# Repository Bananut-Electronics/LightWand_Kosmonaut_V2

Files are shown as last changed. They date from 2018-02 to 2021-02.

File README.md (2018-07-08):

# LightWand_Kosmonaut_V2

Welcome to the LightWand_Kosmonaut_V2 repository. Careful traveller! It is still under development

This _Wiki_ covers the _**LightWand Kosmonaut V2**_ lightpainting tool, an _Open Source_, cheap, easy to made and modify machine tu help the user make awesome detailled photographs through the lightpainting technique.



# What is the LightWand Kosmonaut V2?
The _**LightWand Kosmonaut V2(LWK2)**_ is an Arduino based device which can control LED Stripes in order to display images stored in an SD card. Additionally, it has a number of additional features to use it as a sensor data display device or a simple pattern generator for lightpainting photography.

# So, if this one is V2... where is V1?
The _**LightWand Kosmonaut V1(LWK1)**_ was developped by Pablo dMM in 2015 (The same guy that developped this one) and the repository can be found here:

https://github.com/PabloDMM/LightWand_KosmonautEd

This project was originally based on the first _LightWand_ made by _**Michael Ross**_ in 2014 (http://mrossphoto.com/wordpress32/), please check out his awesome work. The LWK1 inherited form this version the main concept and two SW functions (described in code).

It is a similar tool to the commercial product _**Pixelstick**_ (http://www.thepixelstick.com/).

# Show me what can be done with it.
These are some photos made with this tools, and that should guide you an idea of what is it and how could it be used. None of these photos are processed (further that contrast and brightness and perhaps saturation):

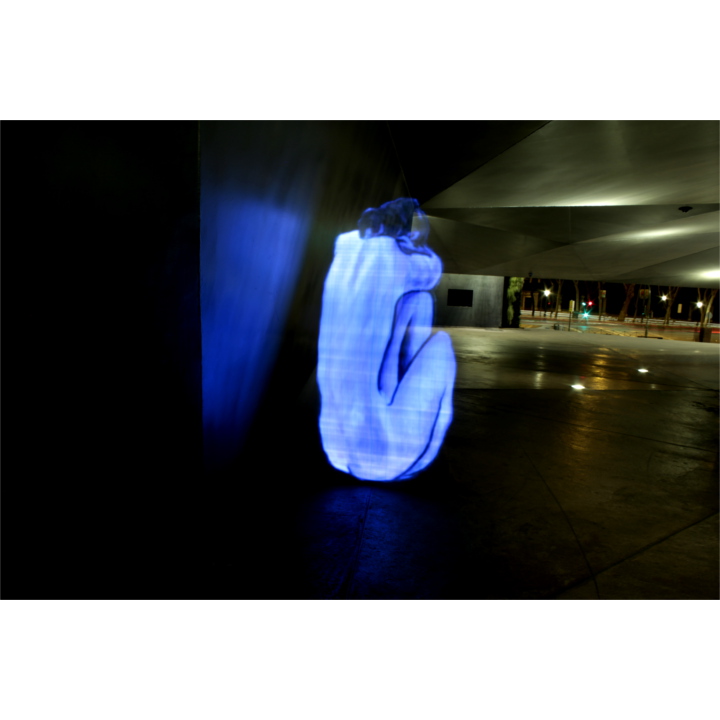
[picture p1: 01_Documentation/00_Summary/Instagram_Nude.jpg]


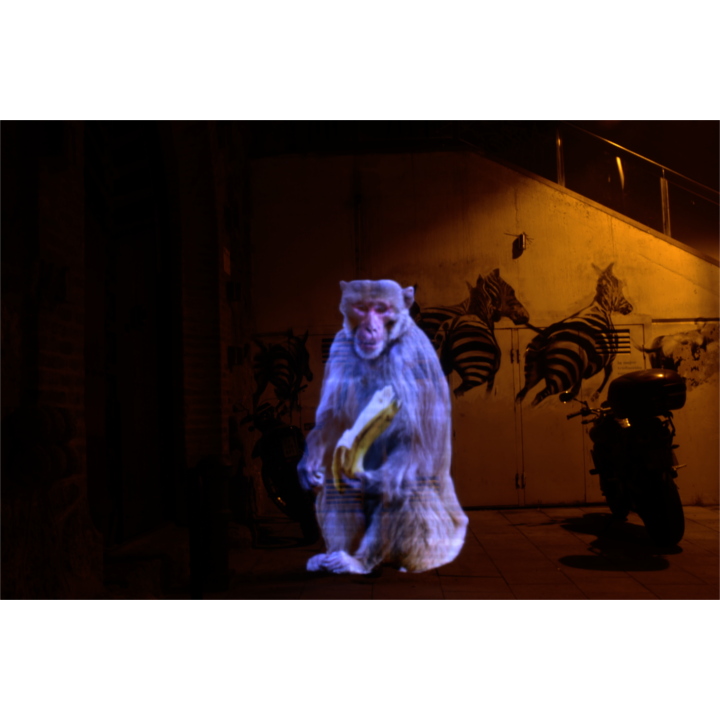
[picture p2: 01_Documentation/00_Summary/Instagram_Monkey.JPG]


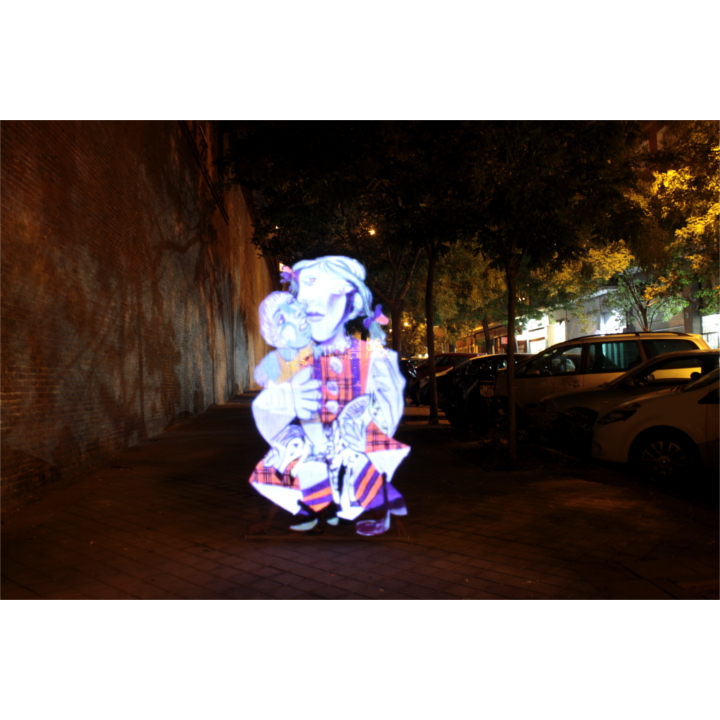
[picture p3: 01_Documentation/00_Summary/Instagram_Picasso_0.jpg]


# What license does it have?
The _**LightWand Kosmonaut V2**_ has a _**CC BY-NC-AT 4.0**_ (https://creativecommons.org/licenses/by/4.0/legalcode)

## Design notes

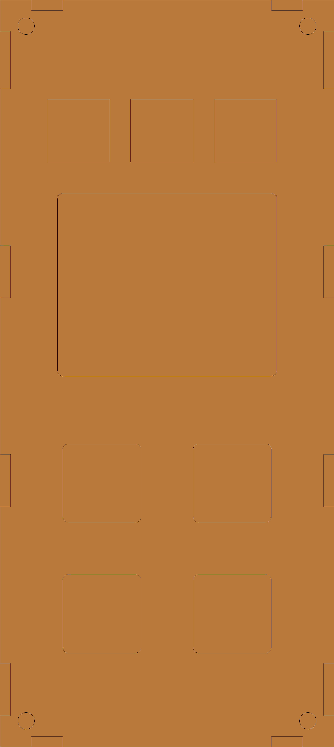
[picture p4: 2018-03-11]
02_Elements/LWK2_MainBoard_Rev_1/03_Mechanics/eagleUp/eagleUp_LWK2_MainBoard_Rev_1_TOP_board_bottom.png

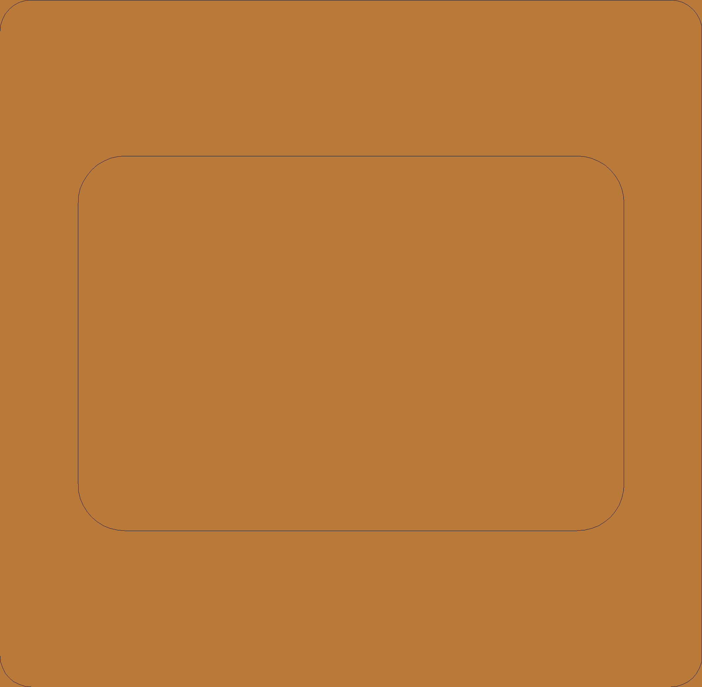
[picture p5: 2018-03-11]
02_Elements/LWK2_MainBoard_Rev_1/03_Mechanics/eagleUp/eagleUp_LWK2_MainBoard_Rev_1_LCD_board_bottom.png

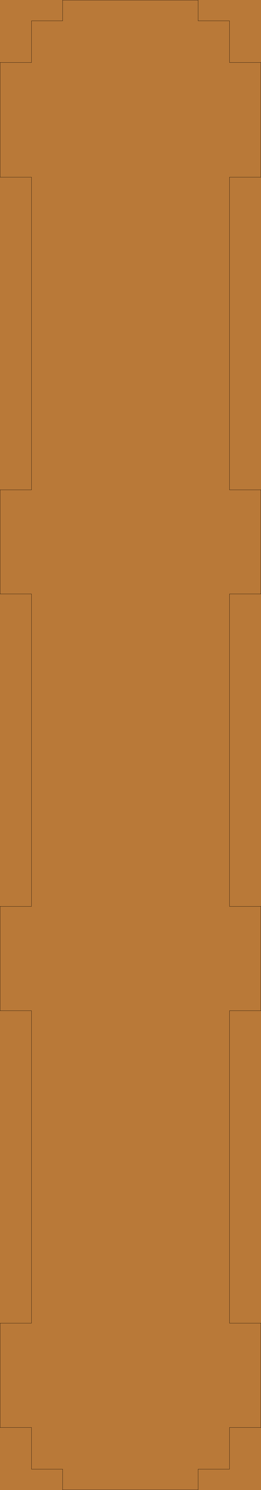
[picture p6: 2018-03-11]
02_Elements/LWK2_MainBoard_Rev_1/03_Mechanics/eagleUp/eagleUp_LWK2_MainBoard_Rev_1_SIDE_LEFT_board_bottom.png

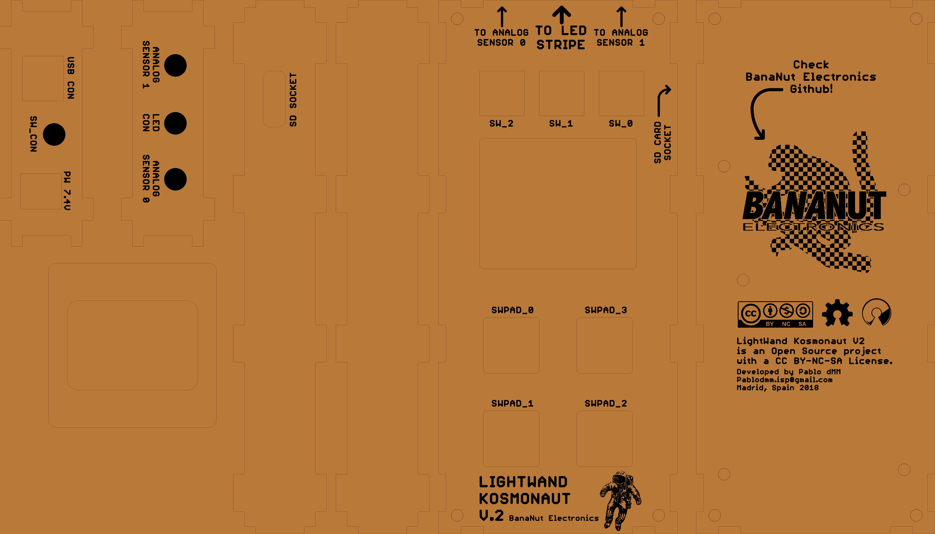
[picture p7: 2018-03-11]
02_Elements/LWK2_MainBoard_Rev_1/03_Mechanics/eagleUp/eagleUp_LWK2_MainBoard_Rev_1_Housing_board_top.png

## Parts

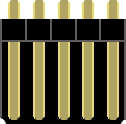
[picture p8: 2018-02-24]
03_Resources/LWK2_ComponentImages/5pin_FemHead.png

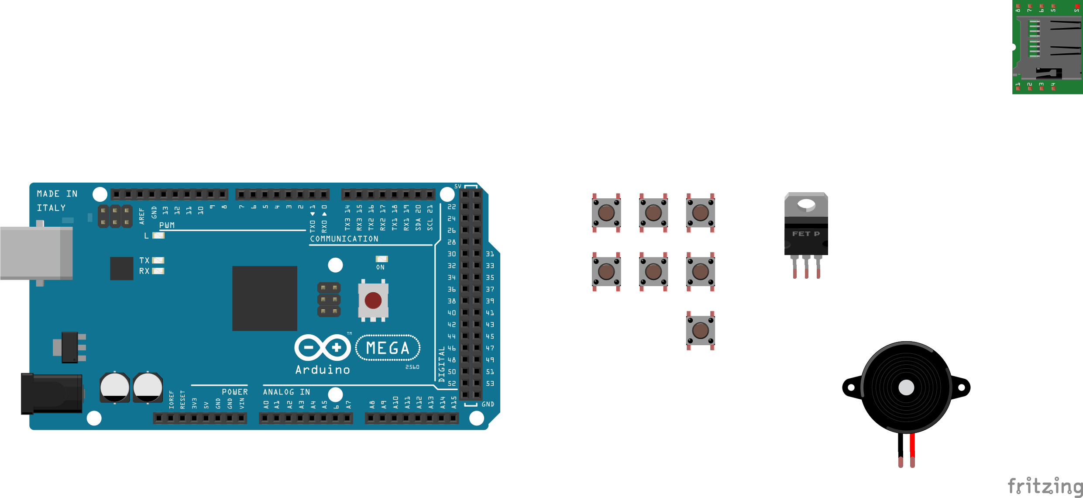
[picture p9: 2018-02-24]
03_Resources/LWK2_ComponentImages/Untitled Sketch_bb - copia.png

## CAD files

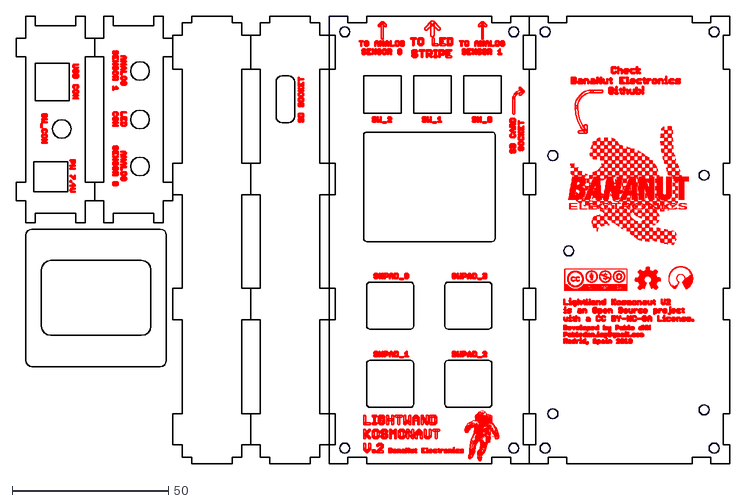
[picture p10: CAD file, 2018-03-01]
02_Elements/LWK2_MainBoard_Rev_1/03_Mechanics/LWK2_MainBoard_Rev_1_Housing.dxf
228.0 x 143.0

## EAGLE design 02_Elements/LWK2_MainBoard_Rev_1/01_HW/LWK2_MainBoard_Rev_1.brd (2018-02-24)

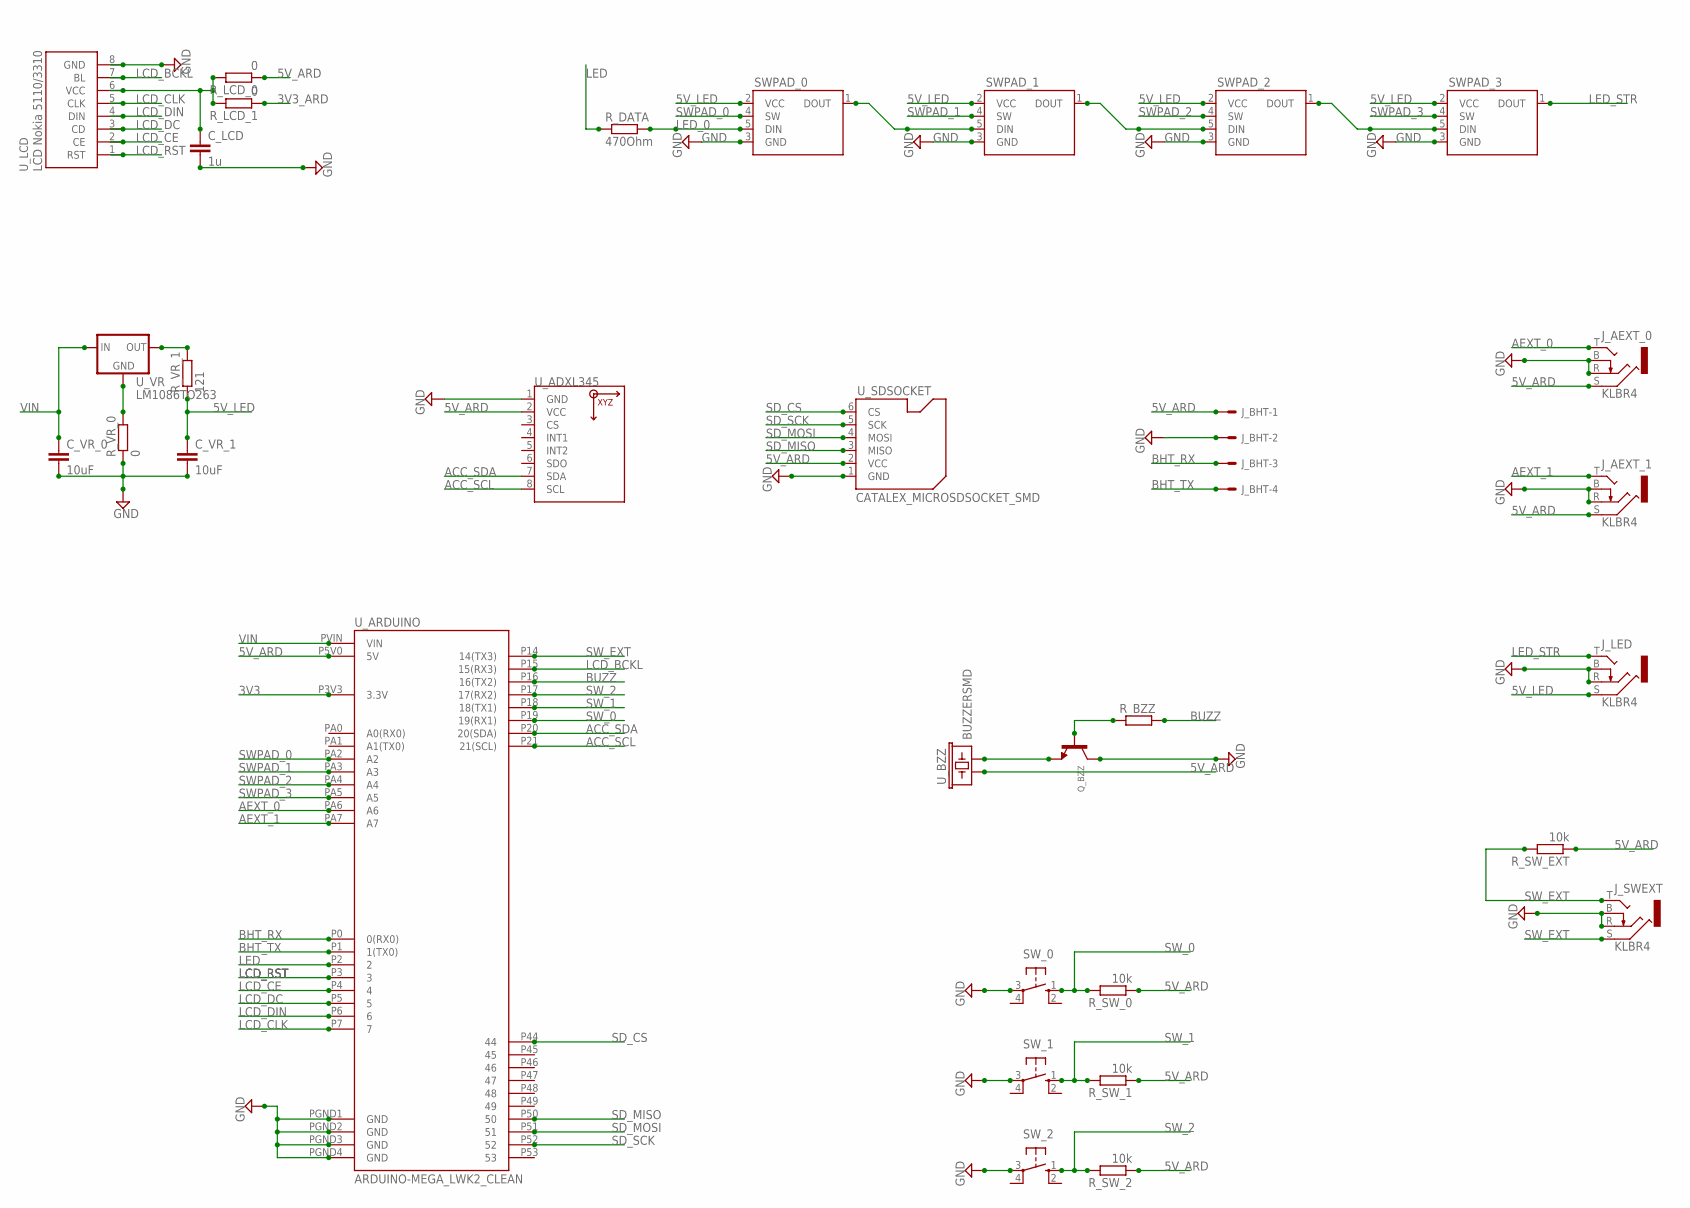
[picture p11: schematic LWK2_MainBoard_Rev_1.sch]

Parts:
C_LCD: 1u; C1206
C_VR_0, C_VR_1: 10uF; C1206
J_AEXT_0, J_AEXT_1: KLBR4
J_BHT: 22-05-7048-04; 7395-04
J_LED: KLBR4
J_SWEXT: KLBR4
Q_BZZ: TRANSISTOR_NPNWIDE; SOT23-WIDE
R_BZZ: R-EU_R1206; R1206
R_DATA: 470Ohm; R1206
R_LCD_0, R_LCD_1: 0; R1206
R_SW_0, R_SW_1, R_SW_2: 10k; R1206
R_SW_EXT: 10k; R1206
R_VR_0: 0; R1206
R_VR_1: 121; R1206
SWPAD_0, SWPAD_1, SWPAD_2, SWPAD_3: MDM_V3_LEDPAD
SW_0, SW_1, SW_2: 40-XX-ROUND; B3F-40XX-ROUND
U_ADXL345: GY-291_ADXL345
U_ARDUINO: ARDUINO-MEGA_LWK2_CLEAN; ARDUINO_MEGA_LWK2_CLEAN
U_BZZ: BUZZERSMD; BUZZER-CMT1603
U_LCD: NOKIA5110
U_SDSOCKET: CATALEX_MICROSDSOCKET_SMD
U_VR: LM1086TO263; TO263

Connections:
3V3: U_ARDUINO.P3V3 (3.3V)
3V3_ARD: R_LCD_1.1
5V_ARD: J_AEXT_0.S, J_AEXT_1.S, J_BHT.1, R_LCD_0.1, R_SW_0.1, R_SW_1.1, R_SW_2.1, R_SW_EXT.1, U_ADXL345.2 (VCC), U_ARDUINO.P5V0 (5V), U_BZZ.P$1 (1), U_SDSOCKET.2 (VCC)
5V_LED: C_VR_1.1, J_LED.S, R_VR_1.1, SWPAD_0.2 (VCC), SWPAD_1.2 (VCC), SWPAD_2.2 (VCC), SWPAD_3.2 (VCC)
ACC_SCL: U_ADXL345.8 (SCL), U_ARDUINO.P21 (21(SCL))
ACC_SDA: U_ADXL345.7 (SDA), U_ARDUINO.P20 (20(SDA))
AEXT_0: J_AEXT_0.T, U_ARDUINO.PA6 (A6)
AEXT_1: J_AEXT_1.T, U_ARDUINO.PA7 (A7)
BHT_RX: J_BHT.3, U_ARDUINO.P0 (0(RX0))
BHT_TX: J_BHT.4, U_ARDUINO.P1 (1(TX0))
BUZZ: R_BZZ.2, U_ARDUINO.P16 (16(TX2))
CS: U_ADXL345.3 (CS)
GND: C_LCD.2, C_VR_0.2, C_VR_1.2, J_AEXT_0.B, J_AEXT_0.R, J_AEXT_1.B, J_AEXT_1.R, J_BHT.2, J_LED.B, J_LED.R, J_SWEXT.B, J_SWEXT.R, Q_BZZ.3 (C), R_VR_0.1, SWPAD_0.3 (GND), SWPAD_1.3 (GND), SWPAD_2.3 (GND), SWPAD_3.3 (GND), SW_0.3, SW_1.3, SW_2.3, U_ADXL345.1 (GND), U_ARDUINO.PGND1 (GND), U_ARDUINO.PGND2 (GND), U_ARDUINO.PGND3 (GND), U_ARDUINO.PGND4 (GND), U_LCD.8 (GND), U_SDSOCKET.1 (GND)
INT1: U_ADXL345.4 (INT1)
INT2: U_ADXL345.5 (INT2)
LCD_BCKL: U_ARDUINO.P15 (15(RX3)), U_LCD.7 (BL)
LCD_CE: U_ARDUINO.P4 (4), U_LCD.2 (CE)
LCD_CLK: U_ARDUINO.P7 (7), U_LCD.5 (CLK)
LCD_DC: U_ARDUINO.P5 (5), U_LCD.3 (CD)
LCD_DIN: U_ARDUINO.P6 (6), U_LCD.4 (DIN)
LCD_PW: C_LCD.1, R_LCD_0.2, R_LCD_1.2, U_LCD.6 (VCC)
LCD_RST: U_ARDUINO.P3 (3), U_LCD.1 (RST)
LED: R_DATA.1, U_ARDUINO.P2 (2)
LED_0: R_DATA.2, SWPAD_0.5 (DIN)
LED_1: SWPAD_0.1 (DOUT), SWPAD_1.5 (DIN)
LED_2: SWPAD_1.1 (DOUT), SWPAD_2.5 (DIN)
LED_3: SWPAD_2.1 (DOUT), SWPAD_3.5 (DIN)
LED_STR: J_LED.T, SWPAD_3.1 (DOUT)
unnamed: R_VR_0.2, U_VR.1 (GND)
unnamed: R_VR_1.2, U_VR.2 (OUT)
unnamed: Q_BZZ.2 (E), U_BZZ.P$2 (2)
unnamed: Q_BZZ.1 (B), R_BZZ.1
SDO: U_ADXL345.6 (SDO)
SD_CS: U_ARDUINO.P44 (44), U_SDSOCKET.6 (CS)
SD_MISO: U_ARDUINO.P50 (50), U_SDSOCKET.3 (MISO)
SD_MOSI: U_ARDUINO.P51 (51), U_SDSOCKET.4 (MOSI)
SD_SCK: U_ARDUINO.P52 (52), U_SDSOCKET.5 (SCK)
SWPAD_0: SWPAD_0.4 (SW), U_ARDUINO.PA2 (A2)
SWPAD_1: SWPAD_1.4 (SW), U_ARDUINO.PA3 (A3)
SWPAD_2: SWPAD_2.4 (SW), U_ARDUINO.PA4 (A4)
SWPAD_3: SWPAD_3.4 (SW), U_ARDUINO.PA5 (A5)
SW_0: R_SW_0.2, SW_0.1 (S), U_ARDUINO.P19 (19(RX1))
SW_1: R_SW_1.2, SW_1.1 (S), U_ARDUINO.P18 (18(TX1))
SW_2: R_SW_2.2, SW_2.1 (S), U_ARDUINO.P17 (17(RX2))
SW_EXT: J_SWEXT.S, J_SWEXT.T, R_SW_EXT.2, U_ARDUINO.P14 (14(TX3))
VIN: C_VR_0.1, U_ARDUINO.PVIN (VIN), U_VR.3 (IN)

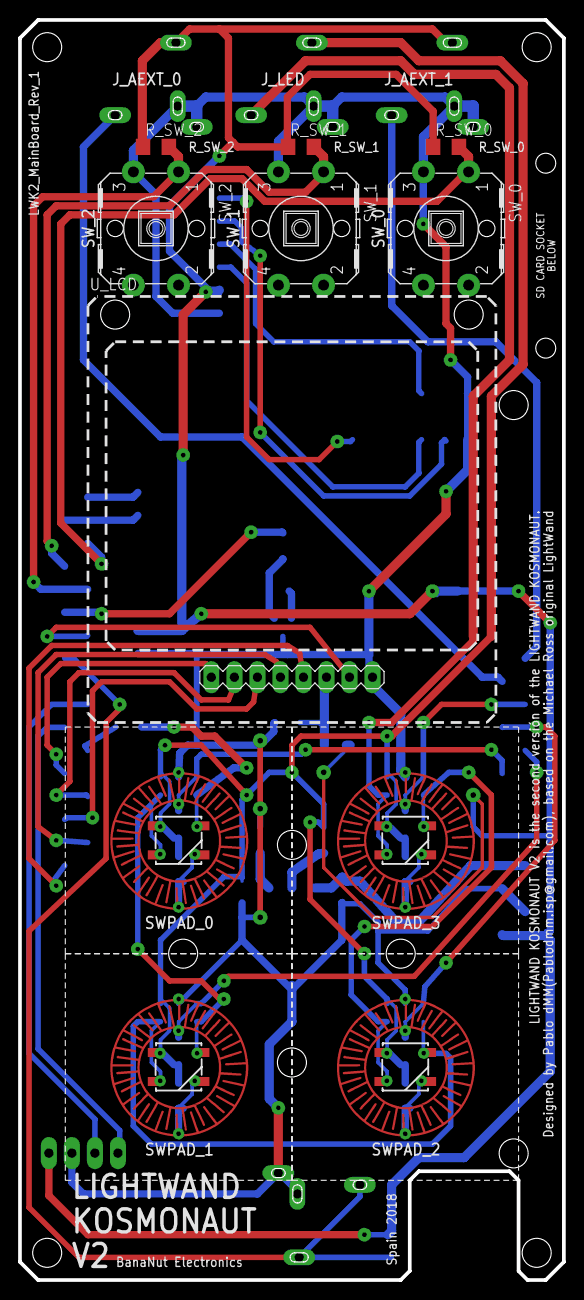
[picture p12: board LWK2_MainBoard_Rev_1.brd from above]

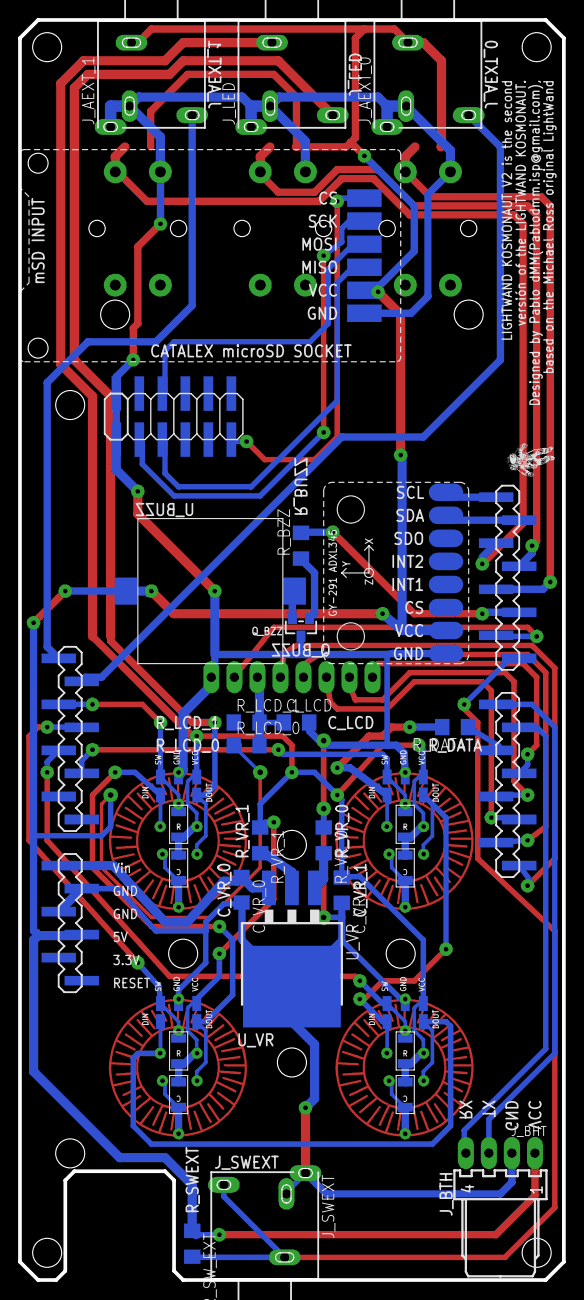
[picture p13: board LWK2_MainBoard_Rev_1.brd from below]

Board: 2 copper layers, 60.0 x 139.0 mm, 32 parts (20 on the bottom side), 40 nets.

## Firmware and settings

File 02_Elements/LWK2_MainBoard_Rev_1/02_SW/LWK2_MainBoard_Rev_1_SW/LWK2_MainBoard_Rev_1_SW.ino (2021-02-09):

/*
LightWand Kosmonaut V2

Code based on Michael Ross original LightWand(2014) and LightWand Kosmanut V1(2015) first written in 2010 and enhaced
by Is0-Mick in 2012.
Apart from the main idea, the following functions have been literally borrowed from the original code:
   setupSDcard()
   GetFileNamesFromSD(File dir)

http://mrossphoto.com/wordpress32/

This code has been written by Pablo de Miguel (pablodmm.isp@gmail.com) in 2018.

This code is intended to run with LightWand Kosmonaut V2 Controller (LWK2_MainBoard_Rev_1), All the information about this
controller can be find in:

TODO LINK GIRHUB ***

This code support direct reading of .pnm RAW files stored in the root directory of a microSD-Card
*/

// Libraries needed
#include <SPI.h>
#include <SD.h>
#include <Adafruit_GFX.h>
#include <Adafruit_PCD8544.h>
#include <Adafruit_NeoPixel.h>

// Gamma Correction LUT from Adafruit
const int GC[256] = {
    0,  0,  0,  0,  0,  0,  0,  0,  0,  0,  0,  0,  0,  0,  0,  0,
    0,  0,  0,  0,  0,  0,  0,  0,  0,  0,  0,  0,  1,  1,  1,  1,
    1,  1,  1,  1,  1,  1,  1,  1,  1,  2,  2,  2,  2,  2,  2,  2,
    2,  3,  3,  3,  3,  3,  3,  3,  4,  4,  4,  4,  4,  5,  5,  5,
    5,  6,  6,  6,  6,  7,  7,  7,  7,  8,  8,  8,  9,  9,  9, 10,
   10, 10, 11, 11, 11, 12, 12, 13, 13, 13, 14, 14, 15, 15, 16, 16,
   17, 17, 18, 18, 19, 19, 20, 20, 21, 21, 22, 22, 23, 24, 24, 25,
   25, 26, 27, 27, 28, 29, 29, 30, 31, 32, 32, 33, 34, 35, 35, 36,
   37, 38, 39, 39, 40, 41, 42, 43, 44, 45, 46, 47, 48, 49, 50, 50,
   51, 52, 54, 55, 56, 57, 58, 59, 60, 61, 62, 63, 64, 66, 67, 68,
   69, 70, 72, 73, 74, 75, 77, 78, 79, 81, 82, 83, 85, 86, 87, 89,
   90, 92, 93, 95, 96, 98, 99,101,102,104,105,107,109,110,112,114,
  115,117,119,120,122,124,126,127,129,131,133,135,137,138,140,142,
  144,146,148,150,152,154,156,158,160,162,164,167,169,171,173,175,
  177,180,182,184,186,189,191,193,196,198,200,203,205,208,210,213,
  215,218,220,223,225,228,231,233,236,239,241,244,247,249,252,255 };

// LWK2_MainBoard_Rev_1 Pin Definition
const int LCD_SCK =  7;   // Definition of LCD Pins
const int LCD_DIN =  6;   // Definition of LCD Pins
const int LCD_DC  =  5;   // Definition of LCD Pins
const int LCD_CS  =  4;   // Definition of LCD Pins
const int LCD_RST =  3;   // Definition of LCD Pins
const int LCD_BL  = 15;   // Definition of LCD Pins
const int SD_MOSI = 51;   // Definition of SD Pins (Just for Info, already set in the SD library)
const int SD_MISO = 50;   // Definition of SD Pins (Just for Info, already set in the SD library)
const int SD_CLK  = 52;   // Definition of SD Pins (Just for Info, already set in the SD library)
const int SD_CS   = 44;   // Definition of SD Pins (Just for Info, already set in the SD library)
const int SWPad_0 = 56;   // SW LED PAD A SWPad_UP (TOP-LEFT)
const int SWPad_1 = 57;   // SW LED PAD B SWPad_DW (BOT-LEFT)
const int SWPad_2 = 58;   // SW LED PAD C SWPad_EXT (TOP-RIGHT)
const int SWPad_3 = 59;   // SW LED PAD D SWPad_SEL (BOT-RIGHT)
const int SW_2    = 17;   // SW Tactile LEFT
const int SW_1    = 18;   // SW Tactile CENTER
const int SW_0    = 19;   // SW Tactile RIGHT
const int SW_EXT  = 60;   // SW Exterior
const int BUZZ    = 16;   // Buzzer Speaker

// Constant Parameters and values
const int LED_SWPAD    =   4; // Number of WS2812B LEDs in the SW LED Pads
const int LED_STR      = 144; // Number of WS2812B LEDs in the LED Stripe

// Constant BMP
const int BYTE_BMP_HEADER            = 122;  // Header for the Windows BitMap with no Opacity STILL DOUBTS
const int BYTE_BMP_HEIGHT            = 22;   // First Byte of File Image Height Header
const int BYTE_BMP_WIDTH             = 18;   // First Byte of File Image Width Header
const int BYTE_BMP_HEADER_LENGTH     = 14;   // First Byte of File Image Length Header
const int BMP_WIDTH_EXPECTED         = 144;  // Expected Width Header
const int BMP_HEADER_LENGTH_EXPECTED = 108;  // Expected Length Header

// Constant Menu IDs
const int menuIDX_MAX  = 8;
const int IDX_FLE    = 0;
const int IDX_MOD    = 1;
const int IDX_BRT    = 2;
const int IDX_DLY    = 3;
const int IDX_BUZ    = 4;
const int IDX_LGT    = 5;
const int IDX_ACC    = 6;
const int IDX_SEN    = 7;
const int IDX_PTT    = 8;

// Constant PTT Pattern Control
const int menuIDX_PTT_MAX = 2;
const int IDX_PTT_R           = 0;
const int IDX_PTT_G           = 1;
const int IDX_PTT_B           = 2;

// Constant Sensor Submenu IDs
const int menuIDX_SEN_MAX   = 6;
const int IDX_SEN_MOD       = 0;
const int IDX_SEN_A0_ONOFF  = 1;
const int IDX_SEN_A0_MIN    = 2;
const int IDX_SEN_A0_MAX    = 3;
const int IDX_SEN_A1_ONOFF  = 4;
const int IDX_SEN_A1_MIN    = 5;
const int IDX_SEN_A1_MAX    = 6;

// Constant SEN Sensor Control
const int SEN_MOD_Max   = 2;
const int SEN_MOD_Point = 0;
const int SEN_MOD_Bar   = 1;
const int SEN_MOD_Color = 2;
const int SEN_A_MAX     = 1000;
const int SEN_A_MIN     = 0;

// Constant BRT Brightness Control
const int BRT_Max   = 100;
const int BRT_Min   = 0;
const int BRT_Step  = 5;

// Constant DLY Delay Control
const int DLY_Max   = 90;
const int DLY_Min   = 0;
const int DLY_Step  = 5;

// Constant MOD Mode Control
const int MOD_Max      = 2;
const int MOD_Min      = 0;
const int MOD_Normal   = 0;
const int MOD_Gif      = 1;
const int MOD_Loop     = 2;

// Constant BZZ Buzzer Control
const int BUZ_Max     = 2;
const int BUZ_Min     = 0;
const int BUZ_Limit   = 0;
const int BUZ_Scale   = 1;
const int BUZ_AllOff  = 2;

// Constant BUZ Buzzer Tones
const int BUZZ_SWPad_UP = 1500;
const int BUZZ_SWPad_DW = 1000;
const int BUZZ_ERROR_H = 5000;
const int BUZZ_ERROR_L = 800;
const int BUZZ_Duration = 50;

// Constant LGT Light Control
const int LGT_Max     = 1;
const int LGT_Min     = 0;
const int LGT_Auto    = 0;
const int LGT_AllOff  = 1;

Adafruit_PCD8544 display = Adafruit_PCD8544(LCD_SCK, LCD_DIN, LCD_DC, LCD_CS, LCD_RST);  //LCD Display Declaration
Adafruit_NeoPixel strip = Adafruit_NeoPixel((LED_STR+LED_SWPAD), 2, NEO_RGB + NEO_KHZ800);         //LED Strip Declaration  

// Control Arrays for SW_Pad LEDS
// ---------------------------------------------------------------------------------------------------------------------
// COLOR RED [0:255]        || COLOR GREEN [0:255]        || COLOR BLUE [0:255]           || Comments
//----------------------------------------------------------------------------------------------------------------------
const byte GEN_R_OFF =  0    ;const byte GEN_G_OFF =  0    ;const byte GEN_B_OFF =   0;    // SW_GENERAL OFF LED COLOR
const byte GEN_R_ON  =  100  ;const byte GEN_G_ON  =  100  ;const byte GEN_B_ON  =   100;  // SW_GENERAL OFF LED COLOR
const byte MENU_0_R  =  50   ;const byte MENU_0_G  =  50   ;const byte MENU_0_B  =   50;   // SW_GENERAL OFF LED COLOR
const byte MENU_1_R  =  0    ;const byte MENU_1_G  =  0    ;const byte MENU_1_B  =   100;  // SW_SCALE ON LED COLOR
const byte MENU_2_R  =  0    ;const byte MENU_2_G  =  100   ;const byte MENU_2_B  =   0;   // SW_SCALE ON LED COLOR
const byte SEL_R     =  0    ;const byte SEL_G     =  50   ;const byte SEL_B     =   50;   // SW_SCALE ON LED COLOR
const byte EXT_R     =  50   ;const byte EXT_G     =  0    ;const byte EXT_B     =   50;   // SW_SCALE ON LED COLOR
const byte ERR_R     =  100  ;const byte ERR_G     =  0    ;const byte ERR_B     =   0;    // SW_SCALE ON LED COLOR

const byte color_MenuLVL[3][3] = {{MENU_0_R, MENU_0_G, MENU_0_B},
                                  {MENU_1_R, MENU_1_G, MENU_1_B},
                                  {MENU_2_R, MENU_2_G, MENU_2_B}};

// Flags for the Pulse Conformer
int SWPad[4]         = {SWPad_0, SWPad_1, SWPad_2, SWPad_3}; // SWPad Pin Array
boolean SWPad_p[4]   = {false, false, false, false};         // SWPad Pulse Conformer Array

const int SWPad_UP      = 0;
const int SWPad_DW      = 1;
const int SWPad_EXT     = 2;
const int SWPad_SEL     = 3;

int menuLVL    = 0;
int menuIDX    = 0;

// Menu Display Definitions
File root;
File dataFile;
String m_CurrentFilename = "";   // Root Filename
int paramFileIDX = 0;            // Variable for the FileIndex  
int paramFileMAX = 0;            // Varialbe for the number of  files in the SD Storage
String m_FileNames[200];         // Variable for the File names(Max 200)
unsigned char R,G,B = 0;

bool dispActive = false; // Active LED Stripe Flag

int paramBUZ    = BUZ_Limit; // Buzzer Parameter
int paramMOD    = 0; // General Function Parameter
int paramBRT    = 75; // Brightness Parameter
int paramDLY    = 20; // Delay Parameter
int paramACC    = 0; // Accelerometer Parameter
int paramLGT    = 0; // Light Mode Parameter

int paramPTT    = 0;
unsigned char paramPTT_R,paramPTT_G,paramPTT_B = 0;

int paramSEN        = 0;    // SEN SubMenu Index
int paramSEN_MOD    = 0;    // SEN Effect Mode
int paramSEN_A0_ON  = 1;    // SEN Analog 0 ON/OFF
int paramSEN_A0_MIN = SEN_A_MIN;    // SEN Analog 0 MIN
int paramSEN_A0_MAX = SEN_A_MAX; // SEN Analog 0 MAX
int paramSEN_A1_ON  = 1;    // SEN Analog 1 ON/OFF
int paramSEN_A1_MIN = SEN_A_MIN;    // SEN Analog 1 MIN
int paramSEN_A1_MAX = SEN_A_MAX; // SEN Analog 1 MAX

int paramFLE_W      = 0;  // Actual Image File Width
int paramFLE_H      = 0;  // Actual Image File Height
int paramFLE_Header = 0;  // Actual Image File Header Byter
int paramFLW_Format = 0;  // Actual Image File Coded Format

void setup(){
  Serial.begin(9600);
  pinMode(LCD_BL, OUTPUT);
  digitalWrite(LCD_BL, HIGH);
  digitalWrite(43,HIGH); //WHOT??
  displaySWPad();
  buzzerStripe_ON();
  setupLCDdisplay();
  setupSDcard();
  strip.begin();
  strip.show();
}

void loop(){
   display_LCD_MENU();   
   readSWPad();
   if(!digitalRead(SW_0)){
    displayStripe();  
   }
   delay(50);
}

void setupLCDdisplay(){
  display.begin();
  display.setContrast(60);
  display.setTextSize(2);
  display.setTextColor(BLACK);
  display.setCursor(0,0);
  display.display();          //Show SplashScreen (Can this be removed??)
  display.clearDisplay();
  display.setTextSize(2);
  display.println("LIGHT WAND");
  display.setTextSize(1);
  display.println("KOSMONAUT V2");
  display.display(); 
  delay(200);
}

void setupSDcard(){
  pinMode(SD_CS, OUTPUT);
  // SD Initialization Routine
  if (!SD.begin(SD_CS)) 
  {
    display.clearDisplay();
    display.setTextSize(2);
    display.println("INI SD FAILED");
    display.display();
    return;
  }
  root = SD.open("/");
  GetFileNamesFromSD(root);
  isort(m_FileNames, paramFileMAX);
  m_CurrentFilename = m_FileNames[0];
}

void GetFileNamesFromSD(File dir){
  int fileCount = 0;
  String CurrentFilename = "";
  while(1) {
    File entry =  dir.openNextFile();
    if (! entry) {
      // no more files
      paramFileMAX = fileCount;
    entry.close();
      break;
    }
    else {
      if (entry.isDirectory()) {
        //GetNextFileName(root);
      }
      else {
        CurrentFilename = entry.name();
        if (CurrentFilename.endsWith(".bmp") || CurrentFilename.endsWith(".BMP")) { //find files with our extension only
          m_FileNames[fileCount] = entry.name();
          fileCount++;
        }
      }
    }
    entry.close();
  }
}

void isort(String *filenames, int n){
  for (int i = 1; i < n; ++i) {
    String j = filenames[i];
    int k;
    for (k = i - 1; (k >= 0) && (j < filenames[k]); k--) {
      filenames[k + 1] = filenames[k];
    }
    filenames[k + 1] = j;
  }
}

void displayStripe(){
  if(menuIDX == IDX_SEN){
    switch(paramSEN_MOD){
      case(SEN_MOD_Point): displayStripe_SEN_MOD_Point(); break;
      case(SEN_MOD_Bar): displayStripe_SEN_MOD_Bar(); break;
      case(SEN_MOD_Color): displayStripe_SEN_MOD_Color(); break;
    }
  }else if(menuIDX == IDX_PTT){displayStripe_PTT();
  }else{displayStripe_BMP();}
}

void displayStripe_SEN_MOD_Point(){
  turnOffLights(); // Turn off SWPad and Display Backlight
  buzzerStripe_START();
  while(digitalRead(SW_1)){
    display_LCD_BUSY();   // Display in LCD Busy Message
    int BRT_Limit = map(paramBRT,0,BRT_Max,0,255);      // Sets the maximum Brightness value
    int pointPos = map(analogRead(A6), paramSEN_A0_MIN, paramSEN_A0_MAX, 0, LED_STR);
    for(int j = LED_SWPAD; j<(LED_SWPAD+LED_STR); j++){ 
      strip.setPixelColor(j, 0, 0, 0);
    }
    strip.setPixelColor(pointPos, G, R, B);
    strip.show();
    delay(paramDLY); 
  }
  interruptDisplayStripe();// Interrupt Stripe Display
  buzzerStripe_END();
}

void displayStripe_SEN_MOD_Bar(){
  turnOffLights(); // Turn off SWPad and Display Backlight
  buzzerStripe_START();
  while(digitalRead(SW_1)){
    display_LCD_BUSY();   // Display in LCD Busy Message
    int BRT_Limit = map(paramBRT,0,BRT_Max,0,255);      // Sets the maximum Brightness value
    int barLength = map(analogRead(A6), paramSEN_A0_MIN, paramSEN_A0_MAX, 0, LED_STR);
    for(int j=LED_SWPAD; j<(LED_SWPAD+barLength); j++){ 
      B = map(analogRead(A7),paramSEN_A1_MIN,paramSEN_A1_MAX,0,BRT_Limit);
      G = map(analogRead(A7),paramSEN_A1_MIN,paramSEN_A1_MAX,0,BRT_Limit);
      R = map(analogRead(A7),paramSEN_A1_MIN,paramSEN_A1_MAX,0,BRT_Limit);
      strip.setPixelColor(j, G, R, B);
    }
    for(int j = (LED_SWPAD + barLength); j<(LED_SWPAD+LED_STR); j++){ 
      strip.setPixelColor(j, 0, 0, 0);
    }
    strip.show();
    delay(paramDLY); 
  }
  interruptDisplayStripe();// Interrupt Stripe Display
  buzzerStripe_END();
}

void displayStripe_SEN_MOD_Color(){
  turnOffLights(); // Turn off SWPad and Display Backlight
  buzzerStripe_START();
  while(digitalRead(SW_1)){
    display_LCD_BUSY();   // Display in LCD Busy Message
    int BRT_Limit = map(paramBRT,0,BRT_Max,0,255);      // Sets the maximum Brightness value
    for(int j=LED_SWPAD; j<(LED_SWPAD+LED_STR); j++){ 
      B = map(analogRead(A7),paramSEN_A1_MIN,paramSEN_A1_MAX,0,BRT_Limit);
      G = 0;
      R = map(analogRead(A6),paramSEN_A0_MIN,paramSEN_A0_MAX,0,BRT_Limit);
      strip.setPixelColor(j, G, R, B);
    }
    strip.show();
    delay(paramDLY); 
  }
  interruptDisplayStripe();// Interrupt Stripe Display
  buzzerStripe_END();
}

void displayStripe_PTT(){
  int BRT_Limit = map(paramBRT,0,BRT_Max,0,255);      // Sets the maximum Brightness value
  turnOffLights(); // Turn off SWPad and Display Backlight
  buzzerStripe_START();
  while(digitalRead(SW_1)){
    display_LCD_BUSY();   // Display in LCD Busy Message
    for(int j=LED_SWPAD; j<LED_SWPAD+LED_STR; j++){ 
      strip.setPixelColor(j, map(paramPTT_G,0,255,0,BRT_Limit), map(paramPTT_R,0,255,0,BRT_Limit), map(paramPTT_B,0,255,0,BRT_Limit));
    }
    strip.show();
    delay(paramDLY); 
  }
  interruptDisplayStripe();// Interrupt Stripe Display
  buzzerStripe_END();
}

void displayStripe_BMP(){
  // Init Routine
  display_LCD_BUSY();   // Display in LCD Busy Message
  turnOffLights(); // Turn off SWPad and Display Backlight
  buzzerStripe_START();
  int BRT_Limit = map(paramBRT,0,BRT_Max,0,255);      // Sets the maximum Brightness value
  // Read the BMP File header
  paramFLE_W,paramFLE_H = 0;
  // Opens File
  char temp[14];
  m_CurrentFilename.toCharArray(temp,14);
  dataFile = SD.open(temp);
  // Rutine to avoid the header of the file
  unsigned char bmpHeader[BYTE_BMP_HEADER];
  dataFile.read(bmpHeader,BYTE_BMP_HEADER);
  // Read the rest of the file
  while(dataFile.available()){
    
    if(!digitalRead(SW_1)){interruptDisplayStripe(); dataFile.close(); return;} // Interrupt Stripe Display
    // File Row Read and Display
    for(int j=LED_SWPAD; j<(LED_STR+LED_SWPAD); j++){ 
      //dataFile.read(); // Opacity Avoidance 
      B = GC[map(dataFile.read(),0,255,0,BRT_Limit)];
      G = GC[map(dataFile.read(),0,255,0,BRT_Limit)];
      R = GC[map(dataFile.read(),0,255,0,BRT_Limit)];

      /*B = map(dataFile.read(),0,255,0,BRT_Limit);
      G = map(dataFile.read(),0,255,0,BRT_Limit);
      R = map(dataFile.read(),0,255,0,BRT_Limit);*/
      strip.setPixelColor(j, G, R, B);
    }
    delay(paramDLY);
    strip.show();
  }  
  // File Close
  dataFile.close();
  // Turn Off LED Stripe
  for(int j=LED_SWPAD; j<(LED_STR+LED_SWPAD); j++){strip.setPixelColor(j,0,0,0);} // Turn Off LED Stripe
  strip.show();  
  // End Routine
  buzzerStripe_END();
  if(paramMOD == MOD_Loop){displayStripe_BMP();} // Display the image in LOOP
  if(paramMOD == MOD_Gif){paramFileIDX++;}       // Place Inde for next image
  turnOnLights(); // Turn off SWPad and Display Backlight
}

void displayStripe_PNM(){
  // Init Routine
  display_LCD_BUSY();   // Display in LCD Busy Message
  turnOffLights(); // Turn off SWPad and Display Backlight
  buzzerStripe_START();
  //readHeader_PNM(); 
  int BRT_Limit = map(paramBRT,0,BRT_Max,0,255);      // Sets the maximum Brightness value
  char temp[14];
  m_CurrentFilename.toCharArray(temp,14);
  File dataFile = SD.open(temp);
  // Rutine to avoid the header of the file
  int countRet=0; // Number of Carriage Return counted
  while(countRet < 4){if(dataFile.read()=='\n'){countRet++;}}
  while(dataFile.available()){
    if(!digitalRead(SW_1)){interruptDisplayStripe();return;} // Interrupt Stripe Display
    // File Row Read and Display
    for(int j=LED_SWPAD; j<(LED_STR+LED_SWPAD); j++){ 
      R = map(dataFile.read(),0,255,0,BRT_Limit);
      G = map(dataFile.read(),0,255,0,BRT_Limit);
      B = map(dataFile.read(),0,255,0,BRT_Limit);
      strip.setPixelColor(j, G, R, B);
    }
    delay(paramDLY);
    strip.show();
  }  
  // File Close
  dataFile.close();
  // Turn Off LED Stripe
  for(int j=LED_SWPAD; j<(LED_STR+LED_SWPAD); j++){strip.setPixelColor(j,0,0,0);} // Turn Off LED Stripe
  strip.show();  
  // End Routine
  buzzerStripe_END();
  if(paramMOD == MOD_Loop){displayStripe_BMP();} // Display the image in LOOP
  if(paramMOD == MOD_Gif){paramFileIDX++;}       // Place Inde for next image
  turnOnLights(); // Turn off SWPad and Display Backlight
}

void readHeader_BMP(){
  char temp[14];
  m_CurrentFilename.toCharArray(temp,14);
  dataFile = SD.open(temp); // Open File
  unsigned char bmpHeader[BYTE_BMP_HEADER];
  dataFile.read(bmpHeader,BYTE_BMP_HEADER);
  paramFLE_W = (bmpHeader[BYTE_BMP_WIDTH] + 256*bmpHeader[BYTE_BMP_WIDTH+1]);
  paramFLE_H = (bmpHeader[BYTE_BMP_HEIGHT] + 256*bmpHeader[BYTE_BMP_HEIGHT+1]);
  paramFLE_Header = (bmpHeader[BYTE_BMP_HEADER_LENGTH] + 256*bmpHeader[BYTE_BMP_HEADER_LENGTH+1]);
  dataFile.close(); // Close File
}

void interruptDisplayStripe(){
  buzzer_ERROR();
  for(int j=LED_SWPAD; j<(LED_STR+LED_SWPAD); j++){strip.setPixelColor(j,0,0,0);} // Turn Off LED Stripe
  strip.show(); 
  turnOnLights(); // Turn off SWPad and Display Backlight
}

void buzzerSWPad(int SWPad_n){
  if(paramBUZ!=BUZ_AllOff){
    switch(SWPad_n){
      case SWPad_UP: tone(BUZZ, BUZZ_SWPad_UP, BUZZ_Duration);break;
      case SWPad_DW: tone(BUZZ, BUZZ_SWPad_DW, BUZZ_Duration);break;
      case SWPad_EXT: tone(BUZZ, BUZZ_SWPad_UP, 2*BUZZ_Duration);tone(BUZZ, BUZZ_SWPad_DW, 2*BUZZ_Duration); break;
      case SWPad_SEL: tone(BUZZ, BUZZ_SWPad_DW, 2*BUZZ_Duration);tone(BUZZ, BUZZ_SWPad_UP, 2*BUZZ_Duration); break;
      default: break;
    }
  }
}

void buzzerStripe_ON(){
  if(paramBUZ!=BUZ_AllOff){
   tone(BUZZ, 500, 100);
   tone(BUZZ, 1000, 100);
   tone(BUZZ, 4000, 100);
  }
}

void buzzerStripe_START(){
  if(paramBUZ!=BUZ_AllOff){
     tone(BUZZ, 3*BUZZ_ERROR_L, 10*BUZZ_Duration);
     tone(BUZZ, BUZZ_ERROR_H, 10*BUZZ_Duration);
  }
}

void buzzerStripe_END(){
   if(paramBUZ!=BUZ_AllOff){
     tone(BUZZ, 3*BUZZ_ERROR_H, 10*BUZZ_Duration);
     tone(BUZZ, BUZZ_ERROR_L, 10*BUZZ_Duration);
   }
}

void buzzer_ERROR(){
  if(paramBUZ!=BUZ_AllOff){
   tone(BUZZ, BUZZ_ERROR_H, 10*BUZZ_Duration);
   tone(BUZZ, BUZZ_ERROR_L, 10*BUZZ_Duration);
  }
}

void readSWPad(){
  for (int i = 0; i < 4; i++){
    if(!digitalRead(SWPad[i])){
      if(!SWPad_p[i]){
        SWPad_p[i]  = true;
        action_MENU(i);
        displaySWPad();
        buzzerSWPad(i);
      }
    }else{
      if(SWPad_p[i]){
        SWPad_p[i]  = false;
        displaySWPad();
      }
    }
  }
}

void displaySWPad(){
  if(paramLGT == LGT_Auto){ // Light All Off Control
    for (int i = 0; i < 2; i++){strip.setPixelColor(i,color_MenuLVL[menuLVL][1],color_MenuLVL[menuLVL][0],color_MenuLVL[menuLVL][2]);}
    strip.setPixelColor(2, EXT_G, EXT_R, EXT_B);
    strip.setPixelColor(3, SEL_G, SEL_R, SEL_B);
    for (int i = 0; i < LED_SWPAD; i++){if(SWPad_p[i]){strip.setPixelColor(i, GEN_G_ON, GEN_R_ON, GEN_B_ON);}}
    strip.show();  
  }
}

void turnOffLights(){
  for (int i = 0; i < 4; i++){strip.setPixelColor(i,0,0,0);} // SWPad Off
  digitalWrite(LCD_BL, LOW);  //LCD Backlight Control OFF;
  strip.show();  
}

void turnOnLights(){
  displaySWPad();
  digitalWrite(LCD_BL, HIGH);  //LCD Backlight Control OFF; 
}

void display_LCD_MENU(){
  m_CurrentFilename = m_FileNames[paramFileIDX];
  display.clearDisplay();
  display.setTextColor(BLACK, WHITE);
  if((menuIDX != IDX_SEN)&&(menuIDX != IDX_PTT)){
    if(paramFileMAX>0){display.println(m_CurrentFilename);}
    else{display.println("NO SD?");}
  }
  switch(menuIDX){
    case IDX_FLE: display_LCD_FLE(); break; // display File Options Submenu
    case IDX_BRT: display_LCD_BRT(); break; // display Brightness Submenu
    case IDX_DLY: display_LCD_DLY(); break; // display Delay Submenu
    case IDX_MOD: display_LCD_MOD(); break; // display Mode Submenu
    case IDX_SEN: display_LCD_SEN(); break; // display Sensor Submenu
    case IDX_BUZ: display_LCD_BUZ(); break; // display Buzzer Submenu
    case IDX_ACC: display_LCD_ACC(); break; // display Accelerometer Submenu
    case IDX_LGT: display_LCD_LGT(); break; // display Settings Submenu
    case IDX_PTT: display_LCD_PTT(); break; // display Patterns Submenu
    default: break;
  }
  display.display();
}

void display_LCD_BUSY(){
  m_CurrentFilename = m_FileNames[paramFileIDX];
  display.clearDisplay();
  display.setTextColor(BLACK, WHITE);
  display.println(m_CurrentFilename);
  display.setTextSize(2);
  display.print("STRIPEBUSY");
  display.display();
  display.setTextSize(1);
}
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

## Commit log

2018-02-24 First Upload
    First upload of current state of the project:
    - HW is done and tested
    - SW still underconstruction
    [LWK2_MainBoard_Rev_1.brd, LWK2_MainBoard_Rev_1.sch, LWK2_MainBoard_Rev_1_Housing.brd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]
2018-03-01 Further Development
    Updated:
    - Final HW of LWK2_MainBoard_Rev_1
    - Final Housing of LWK2_MainBoard_Rev_1 (print with MDF 2MM)
    - Cleaned folders
    - Added photos for the WIKI
    [LWK2_MainBoard_Rev_1_Housing.brd, LWK2_MainBoard_Rev_1_Housing.dxf, LWK2_Nokia5110.brd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]
2018-03-06 SW Update
    Stable version that reads .bmp files with Windows 32bit depth.
    Minor features added or fixed.
    [LWK2_MainBoard_Rev_1_SW.ino]
2018-03-06 Added Final Version
    More Stability and stuff
    [LWK2_MainBoard_Rev_1_SW.ino]
2018-03-11 Documentation Update
    New product photos and refurbished yet still not finished 3D model
    [LWK2_MainBoard_Rev_1_BOT.brd, LWK2_MainBoard_Rev_1_DW.brd, LWK2_MainBoard_Rev_1_Housing.brd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]
2018-07-08 Color Gamma Fixed
    Added Gamma Color correction LUT.
    Added images for tutorial
    [LWK2_MainBoard_Rev_1_SW.ino]

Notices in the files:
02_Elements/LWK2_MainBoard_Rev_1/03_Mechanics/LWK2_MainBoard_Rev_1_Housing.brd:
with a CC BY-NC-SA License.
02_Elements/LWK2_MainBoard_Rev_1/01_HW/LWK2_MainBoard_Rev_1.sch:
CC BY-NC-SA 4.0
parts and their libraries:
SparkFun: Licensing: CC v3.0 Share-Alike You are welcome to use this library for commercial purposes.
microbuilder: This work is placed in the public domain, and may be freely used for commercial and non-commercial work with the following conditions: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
